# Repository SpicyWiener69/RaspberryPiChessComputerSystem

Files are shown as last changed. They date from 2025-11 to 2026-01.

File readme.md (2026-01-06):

### Chess Computer System based on a Raspberry Pi

## Folder Descriptions
```
.
├── UI/:    Chess UI frontend. Allows players to adjust game settings.
├── core/:  program entry point. Handles game logic.
├── ChessBoardPCB/: A PCB board with hall effect sensors designed to sense the position of a chess game. Designed in Kicad7.
└── hardware/: BOM, 3d design files of the system. Designed in Fusion360.
```
More info is written at every subfolder's readme.md file.

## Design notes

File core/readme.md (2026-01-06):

## python Environment setup:

### 1.install python dependencies

### 2. GPIO libraries
RPi.GPIO for Raspberry Pi 5 is deprecated. Users with a Raspberry Pi 5, Navigate to the link below and follow the steps for installation of lgpio, which is a drop-in replacement for RPi.GPIO called  rpi-lgpio.

Note rpi-lgpio and RPi.GPIO cannot be installed at the same time.  

```
https://abyz.me.uk/lg/download.html
```

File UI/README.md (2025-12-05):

# Chess UI on top of LVGL
LVGL provides drivers for many graphics backends.
Legacy framebuffer (fbdev), modern DRM/KMS, Wayland, X11, GLFW3 and SDL2.

Check out this blog post for a step by step tutorial for fbdev
https://blog.lvgl.io/2018-01-03/linux_fb

## Configure drivers and libraries

Adjust `lv_conf.defaults` to select the drivers and libraries that will be compiled by
modifying the following definitions, setting them to `1` or `0`

You can also start with a default config based on the drivers you want to use,
you can find a default config for each graphic driver inside the configs folder.

You can either replace `lv_conf.defaults` manually or using CMake

```bash
cmake -B build -DCONFIG=<config_name> 
```

With `<config_name>` the name of the config without the `.defaults` extension, eg: `configs/wayland.defaults` becomes `wayland`.

## Install dependencies

Be sure to install the required dependencies for the selected drivers by checking
the documentation for each driver here:
https://docs.lvgl.io/master/details/integration/driver/

You can also check the [Dockerfiles](docker/) to get the names
of the packages for various distributions

## Build instructions

### CMake

```
cmake -B build
cmake --build build -j$(nproc)
```

## Run the chess UI application

```
./build/bin/lvglsim
```

## Environment variables

Environment variables can be set to modify the behavior of the driver(s)
Check the documentation of the drivers for more details

### Legacy framebuffer (fbdev)

- `LV_LINUX_FBDEV_DEVICE` - override default (`/dev/fb0`) framebuffer device node.

### EVDEV touchscreen/mouse pointer device

- `LV_LINUX_EVDEV_POINTER_DEVICE` - the path of the input device, i.e.
  `/dev/input/by-id/my-mouse-or-touchscreen`. If not set, devices will
  be discovered and added automatically.

### DRM/KMS

- `LV_LINUX_DRM_CARD` - override default (`/dev/dri/card0`) card.

### Simulator

- `LV_SIM_WINDOW_WIDTH` - width of the window (default `800`).
- `LV_SIM_WINDOW_HEIGHT` - height of the window (default `480`).

## Permissions

By default, unpriviledged users don't have access to the framebuffer device `/dev/fb0`. In such cases, you can either run the application
with `sudo` privileges or you can grant access to the `video` group.

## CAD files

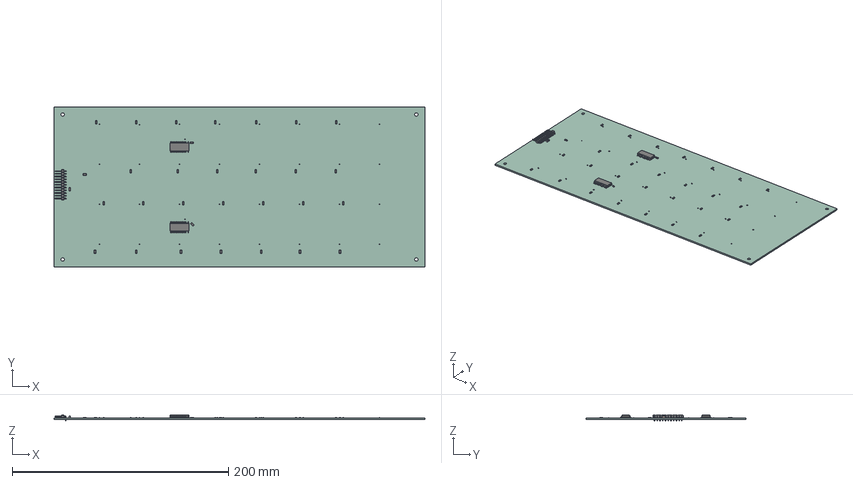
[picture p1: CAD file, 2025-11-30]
ChessBoardPCB/chessboad.step
343.0 x 148.0 x 5.75 mm
chessboad PCB

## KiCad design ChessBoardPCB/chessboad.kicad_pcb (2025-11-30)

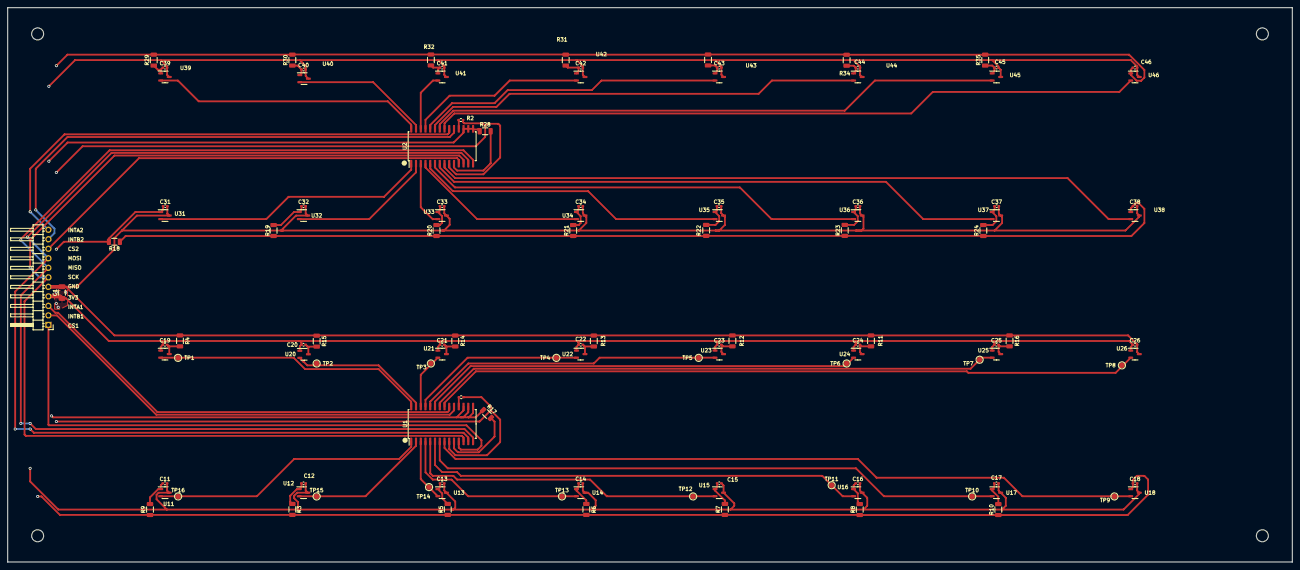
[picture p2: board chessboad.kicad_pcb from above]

Board: 2 copper layers, 343.0 x 148.0 mm, 120 parts (0 on the bottom side), 45 nets.

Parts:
C1: 10uF; C_1206_3216Metric_Pad1.33x1.80mm_HandSolder
C11, C12, C13, C14, C15, C16, C17, C18, C19, C20, C21, C22, C23, C24, C25, C26, C31, C32, C33, C34, C35, C36, C37, C38, C39, C40, C41, C42, C43, C44, C45, C46: 100nF; C_0402_1005Metric_Pad0.74x0.62mm_HandSolder
H1, H2, H3, H4: MountingHole; MountingHole_3.2mm_M3_ISO7380
J1: Conn_01x11_Pin; PinHeader_1x11_P2.54mm_Horizontal
R1, R2: 10k; R_0402_1005Metric_Pad0.72x0.64mm_HandSolder
R3, R4, R5, R6, R7, R8, R9, R10, R11, R12, R13, R14, R15, R16, R17, R18, R19, R20, R21, R22, R23, R24, R28, R29, R30, R31, R32, R33, R34, R35: R; R_1206_3216Metric
TP1, TP2, TP3, TP4, TP5, TP6, TP7, TP8, TP9, TP10, TP11, TP12, TP13, TP14, TP15, TP16: TestPoint; TestPoint_Pad_D1.5mm
U1, U2: MCP23S17_SO; SOIC-28W_7.5x17.9mm_P1.27mm
U11, U12, U13, U14, U15, U16, U17, U18, U19, U20, U21, U22, U23, U24, U25, U26, U31, U32, U33, U34, U35, U36, U37, U38, U39, U40, U41, U42, U43, U44, U45, U46: TMAG4231; SOT-23-3

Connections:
+3.3V: C1.1, C11.1, C12.1, C13.1, C14.1, C15.1, C16.1, C17.1, C18.1, C19.1, C20.1, C21.1, C22.1, C23.1, C24.1, C25.1, C26.1, C31.1, C32.1, C33.1, C34.1, C35.1, C36.1, C37.1, C38.1, C39.1, C40.1, C41.1, C42.1, C43.1, C44.1, C45.1, C46.1, J1.4, R1.1, R2.1, R3.1, R3.2, R5.1, R5.2, R6.1, R6.2, R7.1, R7.2, R8.1, R8.2, R9.1, R9.2, R10.1, R10.2, R18.1, R18.2, R19.1, R19.2, R20.1, R20.2, R21.1, R21.2, R22.1, R22.2, R23.1, R23.2, R24.1, R24.2, R29.1, R29.2, R30.1, R30.2, R31.1, R31.2, R32.1, R32.2, R33.1, R33.2, R34.1, R34.2, R35.1, R35.2, U1.9 (VDD), U2.9 (VDD), U11.1 (Vcc), U12.1 (Vcc), U13.1 (Vcc), U14.1 (Vcc), U15.1 (Vcc), U16.1 (Vcc), U17.1 (Vcc), U18.1 (Vcc), U19.1 (Vcc), U20.1 (Vcc), U21.1 (Vcc), U22.1 (Vcc), U23.1 (Vcc), U24.1 (Vcc), U25.1 (Vcc), U26.1 (Vcc), U31.1 (Vcc), U32.1 (Vcc), U33.1 (Vcc), U34.1 (Vcc), U35.1 (Vcc), U36.1 (Vcc), U37.1 (Vcc), U38.1 (Vcc), U39.1 (Vcc), U40.1 (Vcc), U41.1 (Vcc), U42.1 (Vcc), U43.1 (Vcc), U44.1 (Vcc), U45.1 (Vcc), U46.1 (Vcc)
/CS1: J1.1, U1.11 (~CS)
/CS2: J1.9, U2.11 (~CS)
/INTA1: J1.3, U1.20 (INTA)
/INTA2: J1.11, U2.20 (INTA)
/INTB1: J1.2, U1.19 (INTB)
/INTB2: J1.10, U2.19 (INTB)
/MISO: J1.7, U1.14 (SO), U2.14 (SO)
/MOSI: J1.8, U1.13 (SI), U2.13 (SI)
/SCK: J1.6, U1.12 (SCK), U2.12 (SCK)
GND: C1.2, C11.2, C12.2, C13.2, C14.2, C15.2, C16.2, C17.2, C18.2, C19.2, C20.2, C21.2, C22.2, C23.2, C24.2, C25.2, C26.2, C31.2, C32.2, C33.2, C34.2, C35.2, C36.2, C37.2, C38.2, C39.2, C40.2, C41.2, C42.2, C43.2, C44.2, C45.2, C46.2, J1.5, R4.1, R4.2, R11.1, R11.2, R12.1, R12.2, R13.1, R13.2, R14.1, R14.2, R15.1, R15.2, R16.1, R16.2, R17.1, R17.2, R28.1, R28.2, U1.10 (VSS), U1.15 (A0), U1.16 (A1), U1.17 (A2), U2.10 (VSS), U2.15 (A0), U2.16 (A1), U2.17 (A2), U11.3 (GND), U12.3 (GND), U13.3 (GND), U14.3 (GND), U15.3 (GND), U16.3 (GND), U17.3 (GND), U18.3 (GND), U19.3 (GND), U20.3 (GND), U21.3 (GND), U22.3 (GND), U23.3 (GND), U24.3 (GND), U25.3 (GND), U26.3 (GND), U31.3 (GND), U32.3 (GND), U33.3 (GND), U34.3 (GND), U35.3 (GND), U36.3 (GND), U37.3 (GND), U38.3 (GND), U39.3 (GND), U40.3 (GND), U41.3 (GND), U42.3 (GND), U43.3 (GND), U44.3 (GND), U45.3 (GND), U46.3 (GND)
unnamed: R1.2, U1.18 (~RESET)
unnamed: R2.2, U2.18 (~RESET)
U1A0: TP8.1, U1.21 (GPA0), U26.2 (OUT)
U1A1: TP7.1, U1.22 (GPA1), U25.2 (OUT)
U1A2: TP6.1, U1.23 (GPA2), U24.2 (OUT)
U1A3: TP5.1, U1.24 (GPA3), U23.2 (OUT)
U1A4: TP4.1, U1.25 (GPA4), U22.2 (OUT)
U1A5: TP3.1, U1.26 (GPA5), U21.2 (OUT)
U1A6: TP2.1, U1.27 (GPA6), U20.2 (OUT)
U1A7: TP1.1, U1.28 (GPA7), U19.2 (OUT)
U1B0: TP16.1, U1.1 (GPB0), U11.2 (OUT)
U1B1: TP15.1, U1.2 (GPB1), U12.2 (OUT)
U1B2: TP14.1, U1.3 (GPB2), U13.2 (OUT)
U1B3: TP13.1, U1.4 (GPB3), U14.2 (OUT)
U1B4: TP12.1, U1.5 (GPB4), U15.2 (OUT)
U1B5: TP11.1, U1.6 (GPB5), U16.2 (OUT)
U1B6: TP10.1, U1.7 (GPB6), U17.2 (OUT)
U1B7: TP9.1, U1.8 (GPB7), U18.2 (OUT)
U2A0: U2.21 (GPA0), U46.2 (OUT)
U2A1: U2.22 (GPA1), U45.2 (OUT)
U2A2: U2.23 (GPA2), U44.2 (OUT)
U2A3: U2.24 (GPA3), U43.2 (OUT)
U2A4: U2.25 (GPA4), U42.2 (OUT)
U2A5: U2.26 (GPA5), U41.2 (OUT)
U2A6: U2.27 (GPA6), U40.2 (OUT)
U2A7: U2.28 (GPA7), U39.2 (OUT)
U2B0: U2.1 (GPB0), U31.2 (OUT)
U2B1: U2.2 (GPB1), U32.2 (OUT)
U2B2: U2.3 (GPB2), U33.2 (OUT)
U2B3: U2.4 (GPB3), U34.2 (OUT)
U2B4: U2.5 (GPB4), U35.2 (OUT)
U2B5: U2.6 (GPB5), U36.2 (OUT)
U2B6: U2.7 (GPB6), U37.2 (OUT)
U2B7: U2.8 (GPB7), U38.2 (OUT)

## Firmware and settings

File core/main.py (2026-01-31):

import time
import threading
from threading import Event
from queue import Queue, Empty
import subprocess
import json
import stat
import os
from enum import Enum
from dataclasses import dataclass
import argparse

import numpy as np
import chess
import chess.engine 
from sshkeyboard import listen_keyboard
import RPi.GPIO as GPIO

from board_sensor_array import BoardSensorArray
from board_event_handler import board_uci_move_handler, diff_board_array_to_event
from socket_client import Socket, wait_unix_socket
from gpio_definition import BoardPin

class GameState(Enum):
        WAIT_HUMAN_INPUT = 1
        WAIT_RETRY_MOVE_CONFIRM = 2
        WAIT_COMPUTER_INPUT = 3
        SETUP = 4
        QUIT = 5
        RESET = 6
        IDLE = 7
        WAIT_MANUAL_FOR_COMPUTER = 8


@dataclass
class GameSetup():
    computer_playing:bool
    engine_strength:int
    engine_think_time:int
    engine_side:str
    auto_mover:bool = False

    @classmethod
    def from_json(cls, json_string:str):
        """Create GameSetup instance from JSON string"""    
        try:
            data = json.loads(json_string)
            return cls(**data) 
        except TypeError as e:
            print(f"invalid json, {e}")
            raise

    def __str__(self):
        return f"""
            Game Setup:
            Computer Playing: {self.computer_playing}
            Engine Strength: {self.engine_strength}
            Engine Think Time: {self.engine_think_time}s
            Engine Side: {self.engine_side.capitalize()}
            Auto Mover: {self.auto_mover}
            """
    

class Game:    

    def __init__(self, logging:bool = False):
        self.logging = logging
        
        self.game_state = GameState.IDLE
        self.game_setup = None
        #game context
        self.turn:str =  "white"
        self.board = chess.Board()
        self.board_events:list = []
        self.update_display_flag:bool = False
        
        self.STOCKFISH_PATH = "/usr/games/stockfish"
        self.engine = chess.engine.SimpleEngine.popen_uci(self.STOCKFISH_PATH)
        
        #thread control
        self.sensor_put_queue = threading.Event()
        self.sensor_put_queue.clear()   
        self.running_all_threads = threading.Event()
        self.running_all_threads.set()

        '''
        Top level class "Game" owns GPIO. Responsible for cleanup.
        '''
        self.GPIO = GPIO
        self.GPIO.setmode(GPIO.BOARD)    
        self.board_queue = Queue()
        self.keyboard_queue = Queue()
        self.gui_input_message_queue = Queue()
        self.gui_output_message_queue = Queue()
        
        self.Board_array_node = threading.Thread(target=BoardArrayWorker,args=(self.GPIO,self.running_all_threads,self.sensor_put_queue,self.board_queue),daemon=False)
        
        #closure around listen_keyboard, to pass a queue inside
        cb = lambda key:KeyboardWorker(key,self.keyboard_queue)
        self.Keyboard_listener_node = threading.Thread(target = listen_keyboard,args=(cb,),daemon=True)
        
        self.Gui_node = threading.Thread(target = GuiWorker ,args=('/tmp/chess_ui_socket',self.running_all_threads,self.gui_input_message_queue,self.gui_output_message_queue),daemon=False)
        
        self.Keyboard_listener_node.start()
        self.Board_array_node.start()
        self.Gui_node.start()
        

    def run(self):
        while True:
            self.HandleGameLogic()
            self.HandleDisplayLogic()
            time.sleep(0.03)
    
    def _ResetGameContext(self):
        self.turn:str =  "white"
        self.board.reset()
        self.board_events:list = []
        self.update_display_flag:bool = False
        self.sensor_put_queue.clear()   


    def _SwitchTurn(self):
        assert self.turn == "white" or "black"
        if self.turn == "white":
            self.turn = "black"
        else:
            self.turn = "white"


    def HandleComputerInput(self):
        result = self.engine.play(self.board, chess.engine.Limit(time=self.game_setup.engine_think_time)) 
        print("Stockfish move:", result.move)
        self.board.push(result.move)
        self.update_display_flag = True
        if self.game_setup.auto_mover is False:
            return GameState.WAIT_MANUAL_FOR_COMPUTER

        return self.FetchNextPlayer()


    def HandleGuiInput(self):
        msg:str = self.PollQueue(self.gui_input_message_queue)
        if msg:
            prefix, json_str = msg.split(";", 1)
            if prefix == "start":
                self.game_setup = GameSetup.from_json(json_string=json_str)
                #    &dependency injec
                self.game_setup.auto_mover = False
                print(self.game_setup)
                self.engine.configure({"UCI_LimitStrength": True, "UCI_Elo":self.game_setup.engine_strength})
                print("starting game...")

                return self.FetchNextPlayer()
            elif prefix == "reset":
                return GameState.RESET

        return None
    

    def HandleIdle(self):
        return GameState.IDLE
    

    @staticmethod
    def PollQueue(queue):
        if not queue.empty():
            return queue.get()
        else:
            return None
    

    def FetchNextPlayer(self):
        '''
        Depending on gamemode, return the correct next "player". checks if the outcome is decided.
        '''
        outcome = self.board.outcome()
        if outcome:
            print(outcome)
            return GameState.IDLE

        if self.game_setup.computer_playing:
            if self.turn == self.game_setup.engine_side:
                next = GameState.WAIT_COMPUTER_INPUT
            else:
                next = GameState.WAIT_HUMAN_INPUT
        else:
            next = GameState.WAIT_HUMAN_INPUT
        self._SwitchTurn()
        return next
    
    def WaitManualMoveForComputer(self):
        '''
        In absence of the automover xy system, this function will be called to for human 
        to move for the computer.
        '''
        #assert self.game_setup["auto_moving"] is False
        key:str = self.PollQueue(self.keyboard_queue)
        if key == 'completed action':
            return self.FetchNextPlayer()
        return GameState.WAIT_MANUAL_FOR_COMPUTER


    def HandleRetryConfirm(self):
        #self.sensor_put_queue.clear()
        key:str = self.PollQueue(self.keyboard_queue)
        if key == 'quit':
            return GameState.QUIT
        if key == 'completed action':
            return GameState.WAIT_HUMAN_INPUT

        return GameState.WAIT_RETRY_MOVE_CONFIRM


    def HandleHumanInput(self):
        self.sensor_put_queue.set()
        new_action = self.PollQueue(self.board_queue)
        key:str = self.PollQueue(self.keyboard_queue) 
        if new_action:
            print(f'new move {new_action}')
            self.board_events.append(new_action)

        if key == 'completed action' and len(self.board_events) > 1:
            self.sensor_put_queue.clear()
            print('parsing move:')
            uci_move = board_uci_move_handler(self.board_events,self.board)
            
            if uci_move:
                self.board.push_uci(uci_move.get_uci())
                self.update_display_flag = True
                print(self.board)
                print('_________')
                print(uci_move)
                next = self.FetchNextPlayer()
            else:
                self.update_display_flag = False
                print('retry move')
                next =  GameState.WAIT_RETRY_MOVE_CONFIRM
                
            #reset the board detection buffer
            self.board_events = []
            return next
        return GameState.WAIT_HUMAN_INPUT
    

    def HandleGameLogic(self):
        prev_state = self.game_state 

        gui_msg = self.HandleGuiInput()
        if gui_msg:
            self.game_state = gui_msg

        if self.game_state == GameState.IDLE:
            nextstate = self.HandleIdle()
        elif self.game_state == GameState.WAIT_HUMAN_INPUT:
            nextstate = self.HandleHumanInput()
        elif self.game_state == GameState.WAIT_COMPUTER_INPUT:
            nextstate = self.HandleComputerInput()
        elif self.game_state == GameState.WAIT_RETRY_MOVE_CONFIRM:
            nextstate = self.HandleRetryConfirm()
        elif self.game_state == GameState.RESET:
            nextstate = self.HandleReset()
        elif self.game_state == GameState.QUIT:
            nextstate = self.HandleQuit()
        elif self.game_state == GameState.WAIT_MANUAL_FOR_COMPUTER:
            nextstate = self.WaitManualMoveForComputer()
        else:
            raise ValueError(f"Invalid game state: {self.game_state}")
        
        self.game_state = nextstate 
        if prev_state != nextstate:
            print(f"next game state:{nextstate} ")


    def HandleDisplayLogic(self):
        if self.update_display_flag:
            self.update_display_flag = False
            fen:str = self.board.fen()
            '''
            sends the following string:
                "fen;"+  boardstate representation.
            example:
                "fen;rnbqkbnr/pppppppp/8/8/4P3/8/PPPP1PPP/RNBQKBNR"
            '''
            output:str = "fen;" + fen.split(' ')[0]    
            self.gui_output_message_queue.put(output)
    

    def HandleQuit(self):
        self.engine.quit()
        self.running_all_threads.clear()
        self.Gui_node.join()
        self.Board_array_node.join()
        self.GPIO.cleanup()
        exit(0)
    
    
    def HandleReset(self):
        self._ResetGameContext()
        self.gui_output_message_queue.put("fen;rnbqkbnr/pppppppp/8/8/8/8/PPPPPPPP/RNBQKBNR")
        return GameState.IDLE
    

def GuiWorker(socket_path:str,running,input_queue,output_queue):
    if os.path.exists(socket_path):
        mode = os.stat(socket_path).st_mode
        if stat.S_ISSOCK(mode):
            os.remove(socket_path)

    server_process = subprocess.Popen(
    ["./UI/build/bin/lvglsim"],  
    stdout=subprocess.PIPE,  
    stderr=subprocess.PIPE
    )
    if not wait_unix_socket(socket_path):
        raise RuntimeError(f"{socket_path} not ready")
    
    with Socket(socket_path) as sock:
        while running.is_set():
            #handle inputs
            string  = sock.read_as_str()
            if string:
                input_queue.put(string)

            try:
                outbound = output_queue.get(False)
                print(f'writing outbound:{outbound}')
                sock.write(outbound)
            except Empty:
                continue
            
            time.sleep(0.03)
        print("closing socket...")
        sock.write('quit')
        
        
def BoardArrayWorker(GPIO,running:Event,push_to_queue,output_queue,poll_interval=0.03):
    '''
    thread Owns BoardSensorArray which owns the SPI bus +  4x cs pin. Is responsible for SPI cleanup.

    '''
    board_sensor_array = BoardSensorArray(GPIO=GPIO)
    # prev_board_value = board_sensor_array._read_all()
    # while running.is_set():
    #     #if not push_to_queue.is_set():
    #     push_to_queue.wait()
    #     new_board = board_sensor_array._read_all()
    #     if not np.array_equal(new_board, prev_board_value):
    #         board_event = diff_board_array_to_event(prev_board_value,new_board)
    #         if board_event is None:
    #             #handle board_array_to_uci errors.
    #             continue
    #         prev_board_value = new_board
    #         #if push_to_queue.is_set():
    #         output_queue.put(board_event)
    #         print(f'board event detected:{board_event}') #   
    #     time.sleep(poll_interval)    
    while running.is_set():
        if push_to_queue.is_set() is False:
            first:bool = True
        push_to_queue.wait() 
        new_board = board_sensor_array._read_all()
        if first:
            prev_board = new_board
            first = False
        if np.array_equal(prev_board, new_board):
            continue
        board_event = diff_board_array_to_event(prev_board,new_board)
        if board_event is None:
            #handle board_array_to_uci errors.
            continue
        prev_board = new_board
        output_queue.put(board_event)
        print(f'board event detected:{board_event}') #
        time.sleep(poll_interval)


    board_sensor_array.close_spi()

def ButtonWorker(GPIO:GPIO,queue:Queue,running:Event):
    GPIO.add_event_detect(BoardPin.white_button, GPIO.RISING)  
    GPIO.add_event_detect(BoardPin.black_button, GPIO.RISING)
    while running.is_set():
        inst = [None] * 2
        if GPIO.event_detected(BoardPin.white_button):
            inst[0] = True
            update = True
        if GPIO.event_detected(BoardPin.white_button):
            inst[1] = True
            update = True
        if update:
            queue.put(inst)


#TODO: replace with 2 GPIO buttons PULLUP on each side of chessboard
def KeyboardWorker(key:str,output_queue):
    if key == 'z':
        print('complete action')
        output_queue.put('completed action')

    elif key == 'q':
        output_queue.put('quit')
    

def main():
    parser = argparse.ArgumentParser()
    parser.add_argument("-a",action='store_true',default=False,help = "enable aws logging")
    args = parser.parse_args()
    chess_game = Game(logging = args.a)
    chess_game.run()


if __name__ == "__main__":
    main()
    
    
        

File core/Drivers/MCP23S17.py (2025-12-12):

#!/usr/bin/python

# Copyright 2016-2019 Florian Mueller (contact@petrockblock.com)
#
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

import warnings
import spidev
import time
import threading

class SpiBus:

    '''
    Singleton. shared resource bus with multiple hardware.
    ''' 
    def __init__(self, gpio, bus=0, device=0, speed=50000, mode=0b00):
        self.spi = spidev.SpiDev()
        self.spi.open(bus, device)
        self.spi.max_speed_hz = speed
        self.spi.mode = mode
        self.GPIO = gpio
        self.lock = threading.Lock()
        
    def transfer(self, data, cs_pin=0):
        #with self._lock:
        # Configure SPI for this device
        if (cs_pin != 0):
            # Perform software CS control
            fn = self.GPIO.gpio_function(cs_pin)
            assert fn == self.GPIO.OUT, "cs_pin not initialized to output"
            with self.lock:
                self.GPIO.output(cs_pin, False)
                rx = self.spi.xfer2(data)
                self.GPIO.output(cs_pin, True)

        else:
            with self.lock():
                rx = self.spi.xfer2(data)
        return rx
    def close(self):
        self.spi.close()


class MCP23S17(object):
    """This class provides an abstraction of the GPIO expander MCP23S17
    for the Raspberry Pi.
    It is dependent on the Python packages spidev and RPi.GPIO, which can
    be get from https://pypi.python.org/pypi/RPi.GPIO/0.5.11 and
    https://pypi.python.org/pypi/spidev.
    """
    
    PULLUP_ENABLED = 0
    PULLUP_DISABLED = 1

    DIR_INPUT = 0
    DIR_OUTPUT = 1

    LEVEL_LOW = 0
    LEVEL_HIGH = 1

    """Register addresses as documentined in the technical data sheet at
    http://ww1.microchip.com/downloads/en/DeviceDoc/21952b.pdf
    """
    MCP23S17_IODIRA = 0x00
    MCP23S17_IODIRB = 0x01
    MCP23S17_IPOLA = 0x2
    MCP23S17_IPOLB = 0x3
    MCP23S17_GPIOA = 0x12
    MCP23S17_GPIOB = 0x13
    MCP23S17_OLATA = 0x14
    MCP23S17_OLATB = 0x15
    MCP23S17_IOCON = 0x0A
    MCP23S17_GPPUA = 0x0C
    MCP23S17_GPPUB = 0x0D

    """Bit field flags as documentined in the technical data sheet at
    http://ww1.microchip.com/downloads/en/DeviceDoc/21952b.pdf
    """
    IOCON_UNUSED = 0x01
    IOCON_INTPOL = 0x02
    IOCON_ODR = 0x04
    IOCON_HAEN = 0x08
    IOCON_DISSLW = 0x10
    IOCON_SEQOP = 0x20
    IOCON_MIRROR = 0x40
    IOCON_BANK_MODE = 0x80

    IOCON_INIT = 0x28  # IOCON_SEQOP and IOCON_HAEN from above

    MCP23S17_CMD_WRITE = 0x40
    MCP23S17_CMD_READ = 0x41

    def __init__(self,name, bus:SpiBus, gpio, pin_cs=0, pin_reset=-1, device_id=0x00):
        """
        Constructor
        Initializes all attributes with 0.

        Keyword arguments:
        device_id -- The device ID of the component, i.e., the hardware address (default 0)
        pin_cs -- The Chip Select pin of the MCP, default 0
        pin_reset -- The Reset pin of the MCP
        """
        self.name = name
        self.device_id = device_id
        self.GPIO = gpio
        self._GPIOA = 0
        self._GPIOB = 0
        self._IODIRA = 0
        self._IODIRB = 0
        self._GPPUA = 0
        self._GPPUB = 0
        self._pin_reset = pin_reset
        self._bus = bus
        self._pin_cs = pin_cs #software toggling of CS pin.
        #self._spimode = 0b00
        #self._spi = spidev.SpiDev()
        #self.spi_speed_hz = 6000
        self.isInitialized = False

    # def open_spi_bus(self):
    #     """Initializes the MCP23S17 with hardware-address access
    #     and sequential operations mode.
    #     """
    #     self._setupGPIO()
    #     self._spi.open(self._bus, 0)
    #     self._spi.max_speed_hz = self.spi_speed_hz
    

    def init_MCP23S17(self):
        if self.isInitialized is False:
            #self.setupGPIO()
            self.isInitialized = True
            self._writeRegister(MCP23S17.MCP23S17_IOCON, MCP23S17.IOCON_INIT)

            # set defaults
            for index in range(16):
                self.setDirection(index, MCP23S17.DIR_INPUT)
                self.setPullupMode(index, MCP23S17.PULLUP_DISABLED)

        else:
            warnings.warn("DEVICE HAD BEEN INITIALIZED BEFORE.")
    #TODO:del  this close func 
    def close(self):
        """Closes the SPI connection that the MCP23S17 component is using.
        """
        self._spi.close()
        self.isInitialized = False

    def setPullupMode(self, pin, mode):
        """Enables or disables the pull-up mode for input pins.

        Parameters:
        pin -- The pin index (0 - 15)
        mode -- The pull-up mode (MCP23S17.PULLUP_ENABLED, MCP23S17.PULLUP_DISABLED)
        """

        assert pin < 16
        assert (mode == MCP23S17.PULLUP_ENABLED) or (mode == MCP23S17.PULLUP_DISABLED)
        assert self.isInitialized

        if pin < 8:
            register = MCP23S17.MCP23S17_GPPUA
            data = self._GPPUA
            noshifts = pin
        else:
            register = MCP23S17.MCP23S17_GPPUB
            noshifts = pin & 0x07
            data = self._GPPUB

        if mode == MCP23S17.PULLUP_ENABLED:
            data |= (1 << noshifts)
        else:
            data &= (~(1 << noshifts))

        self._writeRegister(register, data)

        if pin < 8:
            self._GPPUA = data
        else:
            self._GPPUB = data

    def setDirection(self, pin, direction):
        """Sets the direction for a given pin.

        Parameters:
        pin -- The pin index (0 - 15)
        direction -- The direction of the pin (MCP23S17.DIR_INPUT, MCP23S17.DIR_OUTPUT)
        """

        assert (pin < 16)
        assert ((direction == MCP23S17.DIR_INPUT) or (direction == MCP23S17.DIR_OUTPUT))
        assert self.isInitialized

        if pin < 8:
            register = MCP23S17.MCP23S17_IODIRA
            data = self._IODIRA
            noshifts = pin
        else:
            register = MCP23S17.MCP23S17_IODIRB
            noshifts = pin & 0x07
            data = self._IODIRB

        if direction == MCP23S17.DIR_INPUT:
            data |= (1 << noshifts)
        else:
            data &= (~(1 << noshifts))

        self._writeRegister(register, data)

        if (pin < 8):
            self._IODIRA = data
        else:
            self._IODIRB = data

    def digitalRead(self, pin):
        """Reads the logical level of a given pin.

        Parameters:
        pin -- The pin index (0 - 15)
        Returns:
         - MCP23S17.LEVEL_LOW, if the logical level of the pin is low,
         - MCP23S17.LEVEL_HIGH, otherwise.
        """

        assert self.isInitialized
        assert (pin < 16)
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

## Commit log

2025-11-30 Update README with setup and configuration instructions
    Added setup instructions for Python environment and driver configuration.
2025-11-30 Squashed 'ChessBoardPCB/' content from commit bf86e3c
    git-subtree-dir: ChessBoardPCB
    git-subtree-split: bf86e3c46192cbacb9a914b650b1113062c648df
    [chessboad.kicad_pcb, chessboad.kicad_sch, chessboad.step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]
2025-12-05 new reset socket message passing
2025-12-12 fixed ui black/white bug
    [main.py]
2025-12-12 refactor diff_board_array_to_event to board_event_handler.py file
2025-12-16 2nd pcb intergration, success.
2025-12-23 fixed bug at square e4, added new wait state for manual intervention on semi-auto chess system
    [board_sensor_array.py, main.py]
2026-01-22 refactored so board_event_handler won't modify chessboard obj
    [board_event_handler.py, main.py]
